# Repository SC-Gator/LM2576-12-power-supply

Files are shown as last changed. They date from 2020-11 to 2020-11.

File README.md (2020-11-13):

# LM2576-12 based power supply

A simple DIY switching power supply for Eurorack modular synths. This is an attempt to offer a high power but very cheap option for DIY synth makers.

Requires 15V DC input, recommended 3A. You could use a slighty higher voltage but efficiency will decrease. You can decrease input power, if you think you'll use less than the max rating. Use higher power at your own risk!

Have not been able to test the output power, but could be about: +12V/2000mA, -12V/600mA, 5V/300mA. Could vary a lot, especially as 5V regulator takes power from 12V line. Maybe a future redesign will take power from the input line. Be careful to use components (like the inductors) that can support the load.

It is based on the LM2576-12 component, which is a fixed voltage switching step-down voltage regulator. Switching power supplies are supposedly not suitable for audio but I decided to try it because many people use them in their synths, with models like the MeanWell RT-65B, with decent results. In my limited testing, there is no audible noise, and the AC setting on a 4000 count multimeter shows 0 millivolts.

I would be very grateful if someone with a oscilloscope tested this, and could give me feedback on ripple and spikes.

Possible future plans are to make a panel mount module version, an SMT version, and an adjustable output version. Possibly all in one.

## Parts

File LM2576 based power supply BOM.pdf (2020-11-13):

LM2576 based power supply BOM

Id | Designator | QuantitDesignation | Package
1 | C2,C5,C6 | 3 | 2200µF | CP_Radial_D13.0mm_P5.00mm
2 | C1,C4 | 2 | 100µF | CP_Radial_D6.3mm_P2.50mm
3 | L,L2,L3,L4 | 4 | 100µH | L_Radial_D12.5mm_P7.00mm_Fastron_09HCP
4 | C3 | 1 | 4700µF | CP_Radial_D16.0mm_P7.50mm
6 | C9 | 1 | 100µf | CP_Radial_D6.3mm_P2.50mm
7 | D3,D4,D5 | 3 | LED (red) | LED_D3.0mm
8 | D1,D2 | 2 | 1N5822 | D_DO-201AD_P12.70mm_Horizontal
9 | J1,J2 | 2 | Conn_02x08_OddEven PinSocket_2x08_P2.54mm_Vertical
11 C11 | 1 | 100nF | C_Disc_D3.8mm_W2.6mm_P2.50mm
12 C10 | 1 | 10µF | CP_Radial_D5.0mm_P2.00mm
13 J3 | 1 | Barrel_Jack | BarrelJack_Horizontal
15 U3 | 1 | LM7805_TO220 | TO-220-3_Vertical
16 U1,U2 | 2 | LM2576T-12 | TO-220-5_Vertical
17 R1,R2,R3 | 3 | 1KOhm | R_Axial_DIN0207_L6.3mm_D2.5mm_P10.16mm

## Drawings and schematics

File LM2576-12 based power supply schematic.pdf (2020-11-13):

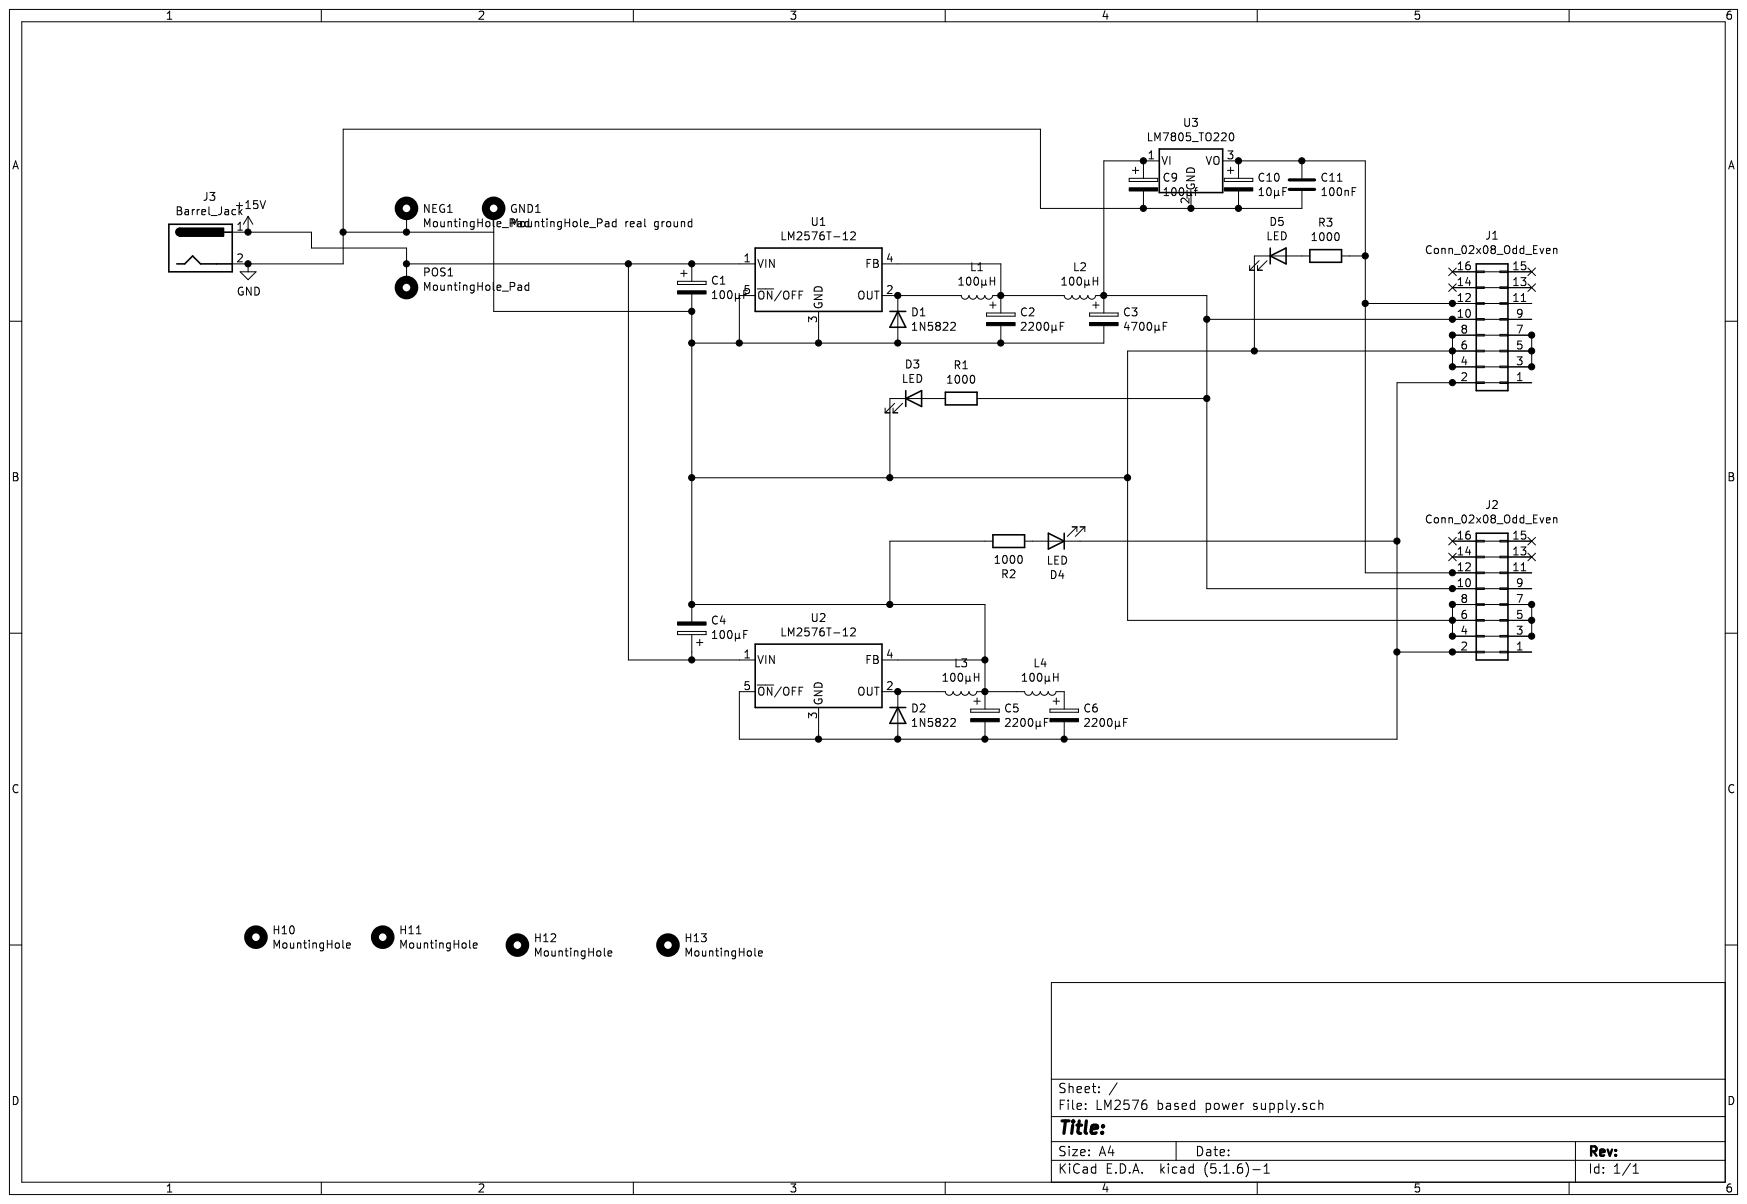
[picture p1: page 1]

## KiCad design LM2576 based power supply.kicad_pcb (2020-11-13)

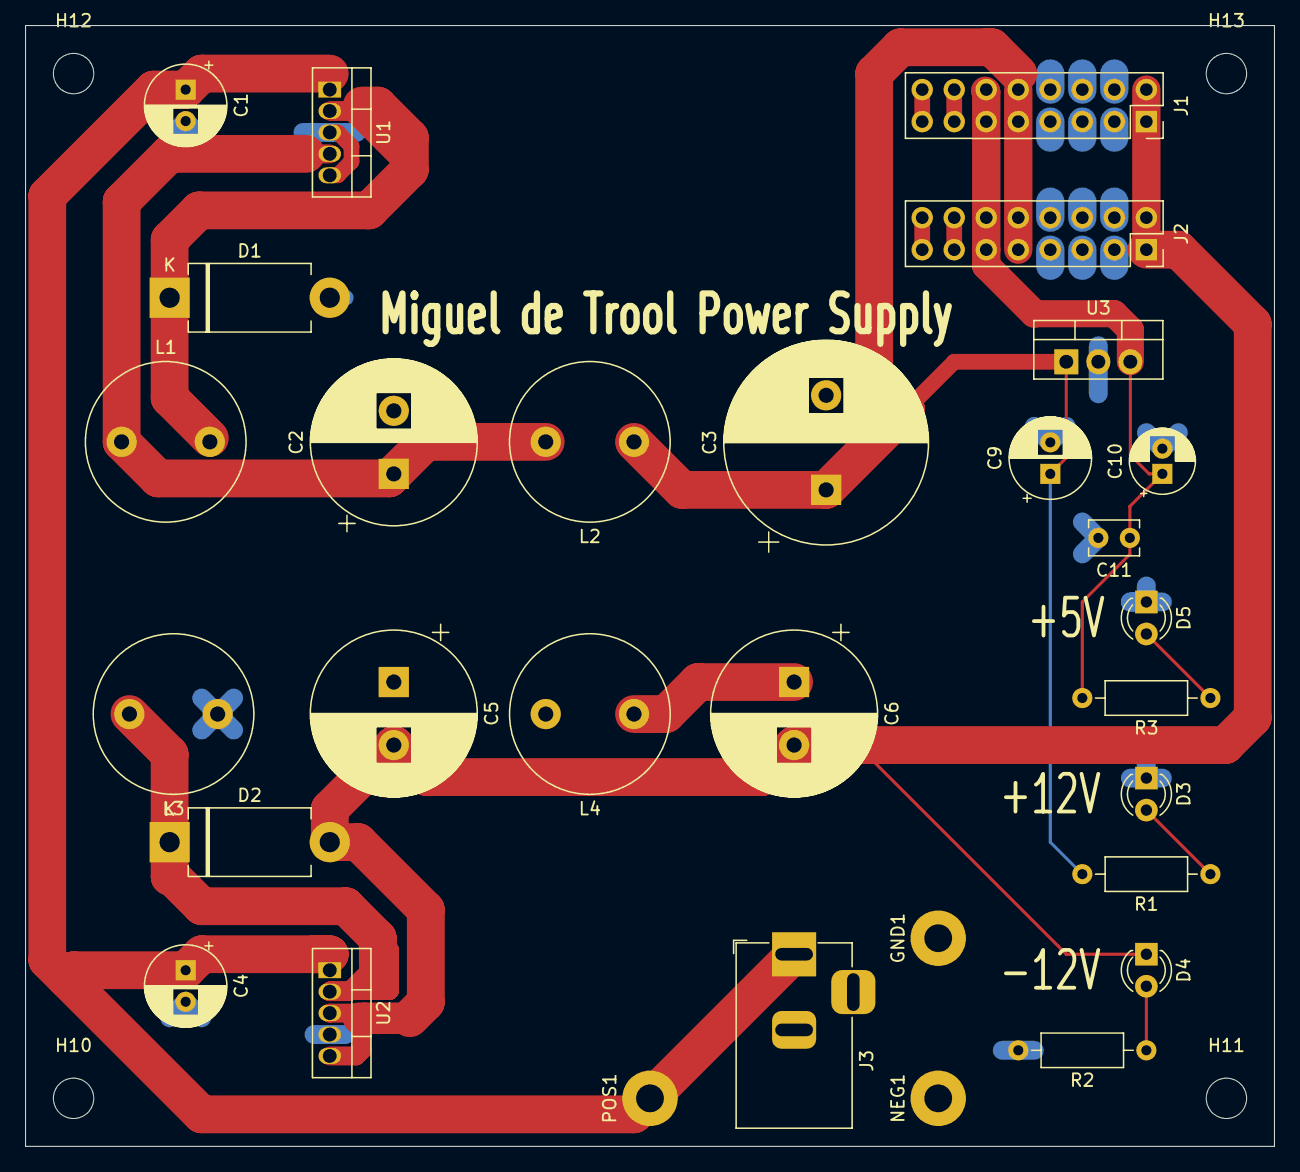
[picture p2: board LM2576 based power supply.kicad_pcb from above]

Board: 2 copper layers, 99.1 x 88.9 mm, 34 parts (0 on the bottom side), 16 nets.

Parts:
C1, C4: 100µF; CP_Radial_D6.3mm_P2.50mm
C2, C5, C6: 2200µF; CP_Radial_D13.0mm_P5.00mm
C3: 4700µF; CP_Radial_D16.0mm_P7.50mm
C9: 100µf; CP_Radial_D6.3mm_P2.50mm
C10: 10µF; CP_Radial_D5.0mm_P2.00mm
C11: 100nF; C_Disc_D3.8mm_W2.6mm_P2.50mm
D1, D2: 1N5822; D_DO-201AD_P12.70mm_Horizontal
D3, D4, D5: LED; LED_D3.0mm
GND1: MountingHole_Pad real ground; MountingHole_2.2mm_M2_Pad
H10, H11, H12, H13: MountingHole; MountingHole_3.2mm_M3
J1, J2: Conn_02x08_Odd_Even; PinSocket_2x08_P2.54mm_Vertical
J3: Barrel_Jack; BarrelJack_Horizontal
L1, L2, L3, L4: 100µH; L_Radial_D12.5mm_P7.00mm_Fastron_09HCP
NEG1: MountingHole_Pad; MountingHole_2.2mm_M2_Pad
POS1: MountingHole_Pad; MountingHole_2.2mm_M2_Pad
R1, R2, R3: 1000; R_Axial_DIN0207_L6.3mm_D2.5mm_P10.16mm_Horizontal
U1, U2: LM2576T-12; TO-220-5_Vertical
U3: LM7805_TO220; TO-220-3_Vertical

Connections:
+15V: C1.1, C4.1, J3.1, POS1.1, U1.1, U2.1
GND: C1.2, C2.2, C3.2, C4.2, C5.1, C9.2, C10.2, C11.2, D1.2, D3.1, D5.1, GND1.1, J1.3, J1.4, J1.5, J1.6, J1.7, J1.8, J2.3, J2.4, J2.5, J2.6, J2.7, J2.8, J3.2, L3.1, L4.2, NEG1.1, R2.2, U1.3, U1.5, U2.4, U3.2
unnamed: C2.1, L1.1, L2.2, U1.4
unnamed: C3.1, C9.1, J1.9, J1.10, J2.9, J2.10, L2.1, R1.2, U3.1
unnamed: C5.2, C6.2, D2.2, D4.1, J1.1, J1.2, J2.1, J2.2, U2.3, U2.5
unnamed: C6.1, L4.1
unnamed: C10.1, C11.1, J1.11, J1.12, J2.11, J2.12, R3.2, U3.3
unnamed: D1.1, L1.2, U1.2
unnamed: D2.1, L3.2, U2.2
unnamed: D3.2, R1.1
unnamed: D4.2, R2.1
unnamed: D5.2, R3.1
unnamed: J1.13, J1.14
unnamed: J1.15, J1.16
unnamed: J2.13, J2.14
unnamed: J2.15, J2.16
